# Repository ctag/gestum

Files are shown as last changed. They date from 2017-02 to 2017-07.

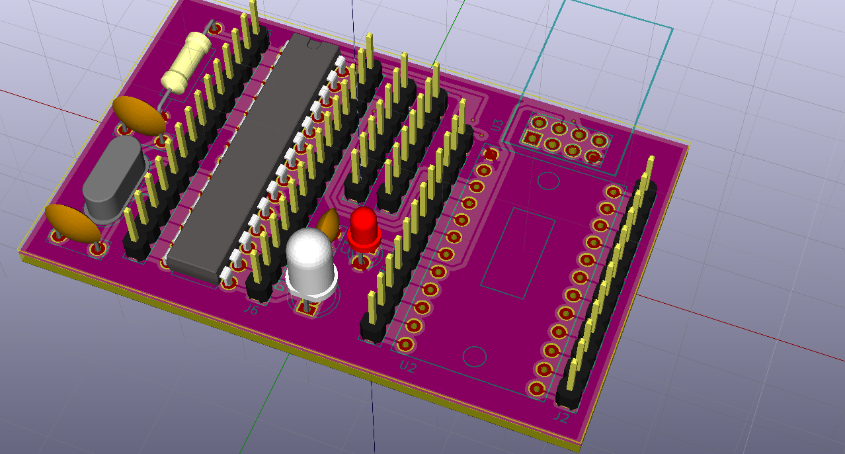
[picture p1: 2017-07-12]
kicad/opisthenar/image/board_render_3d.png

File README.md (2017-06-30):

# Space Sensei (せんせい)

*Firmware which automatically pairs Bosch SensorTec BNO055 library to any number of sensors and shuttles quaternions to a host computer.*

Learn from the sensei.

## Firmware setup

### Serial settings

38400 baud, 8N1

## TLV Packets

TLV (Type-Length-Value-Checksum) is used to minimize data required to send quaternions to host computer.

### Format

* Type - 1 byte opcode (e.g. 0x0C)
* Length - 1 byte unsigned int length of value field.
	* Note - Entire packet is always 'length + 3'
* Value - Raw bytearray.
* Checksum - 1 byte. Validates data integrity.https://68.media.tumblr.com/avatar_ef804b42fa43_128.png
	* Type + Length + [Value1 + Value2 + ValueN] + Checksum = 0x00

### Notes

* Not using preamble/postamble because timeout takes care of synchronization.
	* Timeout is ~30ms. So if comms go down, wait a while and try again.
* Not parsed without length byte.
	* Minimum packet length is 3 bytes.

### Opcodes

Even opcodes are master->mcu. Odd ones are mcu->master.

* 0x02: Heartbeat request (ping)
	* No Value field.
	* Packet: 0x0200FE
* 0x03: Heartbeat response (pong)
	* No Value field.
	* Packet: 0x0300FD
* 0x04: Request System State
	* No Value field.
	* Packet: 0x0400FC
* 0x05: Return System State
	* Value field is 1-2 uint8. 
	* See System state section below.
* 0x06: Request BNO count
	* No Value field.
	* Packet: 0x0600FA
* 0x07: Return BNO count
	* Value field is one uint8
* 0x08: Request BNO Calibration Status
	* Value field is uint8 index of BNO. Must be less than BNO count.
* 0x09: Return BNO Calibration Status
	* Value field is 4 uint8.
	* In order: accel, gyro, mag, sys.
	* Page 48 of datasheet for more.
* 0x0A: Request BNO Quaternion
	* Value field is BNO index.
* 0x0B: Return BNO Quaternion
	* Value field is quaternion. 4 bytes.
* 0xAA: Generic system error
* 0xAB: Generic system error
* 0xAC: Checksum error
* 0xAD: Checksum error
* 0xAE: Timeout with partial packet
* 0xAF: Timeout with partial packet

### System state

Sent as a uint8. Constructed such that any nonzero number indicates a problem (except bootup, which just means wait a bit).

* 0 - Everything's good
* 1 - Bootup (everything's still good)
* 2 - No BNOs detected during scan. Connect them and reboot system.
* 3 - Error initializing BNO. Cycle power to system. Should send erroneous BNO #.

## BNO055

We're using Bosch's BNO055 9-axis fusion IMU. It kinda sucks, and looks like this:

From Adafruit's website

It has a [datasheet](doc/datasheet.pdf), and [C microcontroller library](https://github.com/BoschSensortec/BNO055_driver), with a [3rd party guide](doc/IntegrateBNO055.pdf) to help you integrate the library to your project.

### Bootup

On boot the BNO automatically falls into calibration mode. The space sensei firmware will wait until the minimum (maybe) calibration is met. Then it will proceed to normal operation.

On the debugging hardware, an LED is yellow during calibration, then switches to green for normal operation.

For NDEF mode (which we're using) the most basic calibration required is magnotometer (rotate sensor 360 like a compass).

### Calibration

Also listed in BNO datasheet page 47. Reiterated here for convenience.

* Mag
	* Rotate sensor in a circle like a compass.
* Gyro
	* Place sensor in a stable position for a few seconds.
* Accel
	* Place the device in 6 different stable positions for a period of few seconds to allow the
accelerometer to calibrate.
	* Make sure that there is slow movement between 2 stable positions
	* The 6 stable positions could be in any direction, but make sure that the device is lying at
least once perpendicular to the x, y and z axis.

Calibration status (as returned by command) is 0-3 for each with 0 being uncalibrated and 3 being nicely calibrated.

## Timing

Atmega328 runs at 16,000,000Hz. 0.000000063 seconds per tick.

BNO supposedly runs in NDEF mode at 100Hz. Haven't determined if it can be polled faster than this but with only 100Hz worth of valid data.

Esp8266 runs at a hair faster than the 4th order element of the Laplace transform of the function which defines cumulative average lava flow rates in North America but only up to the 19th century. Which is to say it actually runs at 80Mhz but has a lot of firmware cruft and I have no idea if that's a net positive or not.

## ESP8266

[notes here](esp/esp.md)

## Dev Notes

* 3 BNOs + TCA mux is right at the edge of the max power draw for my ftdi cable..
* Dupont/header connections make i2c unreliable. For implementation either solder connections or remove any stress/movement in wire connections.
* Firmware startup has a ~1 second delay which allows BNOs to boot. Is mentioned in the BNO datasheet.

## To Do  

Explain checksumming

Add quaternion member byte order in return tlv

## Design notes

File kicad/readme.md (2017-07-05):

# KiCAD

These files contain the PCB designs for space sensei.

## Opisthenar

Opisthenar is the back of the hand, where we intend to mount the central processing and communication elements of this sensor network.

## Phalanx

Phalanges are the bone segments in fingers, where we intend to mount the individual BNO055 sensors that report back to the Opisthenar PCB.

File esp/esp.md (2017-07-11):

# ESP Link

Using esp-link firmware on Wemos D1 mini board (esp8266). Also works on ESP-01 (smaller board).

They're eccentric and I don't like them, just like Tingle here.

## Devices

We're using two types of ESP8266 boards: [D1 Mini by WeMos](https://wiki.wemos.cc/products:d1:d1_mini) and [ESP-01 by AI Thinker](http://ecksteinimg.de/Datasheet/Ai-thinker%20ESP-01%20EN.pdf).

WeMos D1 is good for debugging and testing, but I'd like a final product to have the esp-01 because it's much smaller.

Command to check flash memory size:

	esptool --port /dev/ttyUSB3 --baud 115200 flash_id

### D1 Mini

The D1 mini has 8MB of flash, runs at 80MHz, costs less than $10, and is pretty big. Can be programmed over built-in usb port. Accepts 3V3 or 5V VCC.

Image of D1 Mini

### ESP-01

The esp-01 has 1MB of flash, runs at 40MHz, costs less than $5 and is pretty small. Can be programmed with an [external FTDI adapter](http://www.14core.com/wiring-and-upgrading-the-esp8266-firmware-via-ttl-uart-bridge/) and a sacrifice to the gods of poor PCB design. Accepts only 3V3 officially... but will work with 5V and get scalding hot.

The ESP-01 has two onboard LEDs, red and blue. Red is connected to power, blue is connected to the board's TX.

ESP-link adds an external green LED for wireless status. It is active-low; 3.3V draw.

Image of esp-01

## Installation

From the [esp-link flashing guide](https://github.com/jeelabs/esp-link/blob/master/FLASHING.md), download release archive and extract it.

Command to flash D1 mini:

    esptool --chip esp8266 --port /dev/ttyUSB3 \
    write_flash -fm dio -fs detect -ff 20m \
    0x00000 boot_v1.6.bin 0x01000 user1.bin \
    0x3fc000 esp_init_data_default.bin 0x7e000 blank.bin \
    0x3fe000 blank.bin 

This command is a mash-up of the [instructions for flashing esp-link](https://github.com/jeelabs/esp-link/blob/master/FLASHING.md) and Wemos's d1 mini [flashing guide](https://wiki.wemos.cc/tutorials:get_started:revert_to_at_firmware).

Default AP ssid: `ESP_XXXXXX`

Command to flash ESP-01:

	esptool --chip esp8266 --port /dev/ttyUSB3 \
	write_flash -fm dio -fs detect -ff 40m \
	0x00000 boot_v1.6.bin 0x01000 user1.bin \
	0xfc000 esp_init_data_default.bin \
	0xfe000 blank.bin

Default AP ssid: `AI-THINKER_XXXXXX`

By default the esp-link firmware creates an AP which you connect to and then browse the 192.168.4.1 IP address's site, which is configuration for the system.

## Configuration

Connect to the `ESP-XXXXX` network. You should receive a DHCP address in 192.168.4.0/24.

The ESP runs mDNS, so you can connect to the ESP as either `esp-link` hostname or `192.168.4.1` IP address.

Telnet is primarily on port 23. There is a 5 minute timeout for inactivity, after which you need to reconnect.

I have debug logging turned off to keep junk from being sent to the microcontroller.

## Serial Connection

To connect the esp's telnet to a virtual serial port:

    sudo socat TCP4:192.168.4.1:23 PTY,link=/dev/ttyS0

Then open `/dev/ttyS0` with root.

If your machine uses generic DNS, then you can replace the above IP with the esp's mDNS hostname: `esp-link`

Reference:

http://technostuff.blogspot.com/2008/10/some-useful-socat-commands.html

Apparently you can also just use normal TCP, but I haven' tested it yet.

## Testing

With a simple loopback test (FTDI cable wired to the d1 mini) the latency from serial to telnet was imperceptible. Latency from telnet to serial was ~300ms.

## Dev Notes

esp-link will close the telnet connection after 5 minutes of inactivity. Be warned, software needs to be able to account for this and reconnect.

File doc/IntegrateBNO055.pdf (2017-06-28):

How to Integrate the Bosch BNO055 Library into your Tiva Launchpad Project A How-To Guide
By Phillip Dupree
Mechatronics Lord

So you want to integrate the BNO055 Bosch-Sensortec C Library into your Tiva Launchpad Project? You poor bastard. Good luck. Quick note before you get started, this guide should be extremely helpful in showing anyone how to integrate the Bosch bno055 library into their microcomputer project, regardless of whether they are using a Tiva Launchpad microcomputer or not. The microcomputer I’m using is the TM4C123GXL. Now let the games begin.

### Chapter 1: Preliminary Reading

1A: You’re In Trouble.
Because this is, unfortunately, a massive pain. But there is hope for you, especially if you’re extremely familiar with:
- I2C Protocol
- C Programming Language (advanced)
- TivaWare Library
- TivaWare I2C Library and what the I2CmasterControl Function is actually doing on an I2C Protocol level.
- The bno055 datasheet, particulary the section on I2C Communication.

If not, here is where you start.

1B: Get Reading
For I2C Protocol, this is a very good online tutorial that goes over both I2C Protocol and how to use the Tiva to set it up. The video is “TM4C123 Tutorial: I2C Communications” by AllAboutEE on Youtube. This dude is a baller and I want him to be my friend. Watch this video three or four times (seriously) and take notes. Once you actually feel comfortable with how I2C Protocol works (SCL line, SDA line, master, slave, acks, nacks, start bit, stop bit, etc), then move on. I highly recommend you google around and read a few articles on I2C Protocol as well to make sure everything is clicking.

Next move on to the tivaware library. Download the document “TivaWareTM Peripheral Driver Library: User’s Guide” from Texas Instruments. Skip to section 17: Inter-Integrated Circuit (I2C) and read up on all the functions. Spend a good time on the initialization functions and I2Cmaster Control.You should see how they do all the different things you learned about my studying I2C beforehand.

Unfortunately we’re not nearly done with absorbing all the information you’ll need to even stand a chance of integrating Bosch’s bno055 library into your project. It’s critical that you understand not just I2C protocol, but how the bno055 works with I2C. Can the bno055 handle successive reads and writes, or do you have to send and/or read one byte at a time? What clock rate does the bno055 require for its I2C communication? What is its default slave address? You get the point. Download the bno055 datasheet from Bosch-Sensortec or Adafruit. You really need to read it from cover to cover, but for now scour Section 4.6, I2C Protocol (referred to throughout the guide as 4.6). Read it again, and again. We’ll be referring back to this throughout the guide.

If you’re doing this right you should be seeing a problem by now. Now you know the specifics of how you write to the bno055 via I2C. Like, if you want to write a byte you have to send a start bit then, then the slave address, then get an ack back from the bno055, then send the register address, get an ack back, don’t send a stop bit yet, etc…but do you know how to do any of that? Not really. You have this big TivaWare functions that initialize I2C and send a slave address, data byte, then a nack, but you probably don’t know how to do complicated stuff like the Read of a bno055 register requires. Writing a slave address then register address, getting an ack back, being sure not to send a stop bit, then sending a read command + register address, etc..what you need to know is exactly what the I2C Master Control commands are doing. There are 8 of them, and to construct the bno055 i2c read and write functions you’ll need to know exactly what they do.

In order to do that, download “Using Feature Set of I2C Master on TM4C129X Microcontrollers” written by Amit Ashara, from the Texas Instruments website. It is an Application Report, SPMA073 – July 2015. Plug all that and it should pop up in google. Amit Ashara is a total badass who balls so hard, you don’t even know. He’s a huge help and lord and master of the TI forum. Read this document from cover to cover and cross-analyze it with the I2C Protocol section of the bno055 datasheet. You should now understand how, in order to send a write command, you’ll need to use the I2C Master Burst Send Start and Burst Send Finish commands, and for the more complicated bno055 read commands, you’ll need to use a combination of the Burst Send Start, Single Receive, Burst Receive Continuous, and Burst Receive Finish commands, depending on how many bytes you’re trying to read at once.

We’d be nearing the end if we were simply writing our own I2C Library using TivaWare to communicate with the bno055. And in a lot of ways, that would be much easier than what we are attempting to do. Stop here if you want to make a few read and write register fuctions. You now know enough to do so. But for you few brave souls who want to integrate Bosch Sensortec BNO055 sensor driver library into their projects, which will give you the ability to get huge amounts of data from the bno055 with one line function calls, then continue.

### Chapter 2: Shit Gets Real (The Library, What It Does, and Other Concerns)

2A: Getting Started. Download the driver library. It only consists of three files: bno055.h, bno055.c, and

bno055_support.c. Integrate the first two into your project as usual and don’t forget to add the include files into your relevant modules. Spend a lot of time reading through all three files. The support file is a rather nebulous cluster of badly written examples, while the first two are your standard library files.

First of all, download and read “BNO055 Quick Start Guide” from Bosch Sensortec. It’s only 9 pages so read it through several times spending most of your time on page 7, the example code (if you are unfamiliar with the bno055 to begin with this guide would be a good place to start). You should now understand that in theory, this library can make your life pretty easy, with powerful functions that allow you to change the mode and give you access to all the data the IMU has to offer. It’s a generic C library to go with any microcomputer, so all you really have to do is:
a. Copy the entire initialization routine from the Quick Start Guide (steps 1 – 5)
b. Select whatever mode you want and start calling functions to get your data
c. Figure out Step 3 in the Quick Start Guide example code, in which you write your own I2C Functions for reading and writing and link them to the API communication pointers. On the right side of these functions you insert your own i2c read and write functions (BNO055_I2C_bus_read and _write are just holders for your own functions.) Easy, right?

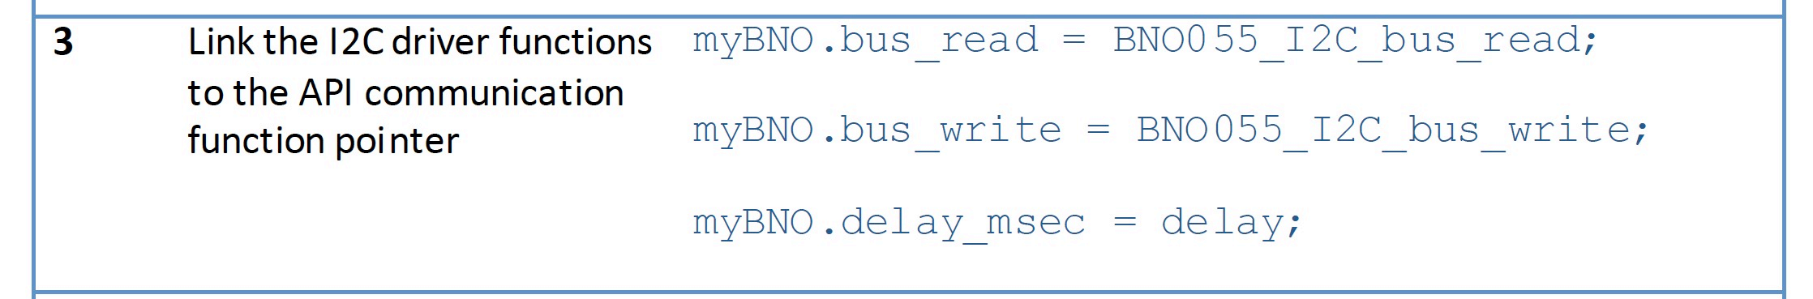
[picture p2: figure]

Figure 1: Example Code, Step 3

Hell no.

The problem is that how these functions need to be written is completely undocumented. What arguments do these functions require? Do they need to save their data to an array somewhere? What are they returning? Do they return anything? Do the functions need to be able to internally handle reading and/or writing multiple bytes?

You’ll have to parse together the answers to these questions and many more, in little infuriating painful bits in pieces, by reading 4.6 (which I’ve already had you study), and dragging yourself through the library files.

If your C is very good and you have no problem reading about structs and pointers, this library may be moderately straight-forward to you. If you’ve never used structs, pointers, referencing, passing, and that sort in your moderately simple C code before (like me), this library will be an unintelligible clusterfuck. Make no mistake, this library is advanced C. It’s not just you. So read through the library as best you can, take a break and get some coffee, then come back and spend a few hours reading about structs and pointers. Everything about pointers. Pointers and referencing, pointers as function arguments, pointers pointers pointers. Let it sink in. Write some simple example programs. Take another break, come back and read about pointers and arrays and pointers to an array. Let that sink in. Sleep on it all.

Now it’s morning and the library will make a bit more sense. I can’t explain to you very well how it works, but I can give you some ideas.

2B: The Header File
Open up bno055.h, the header file. A struct called bno055_t is created to hold all the core information of the chip, including the chip ID, softwar rev ID, i2c device address, and most importantly, the bus write and read function pointers. This struct is created in the header file under STRUCTURE DEFINITIONS.
There are structs created to hold the data from accelerometer, magnetometer, gyro, calibration, etc. These structs hold the different components for each of these measurements and are also found in the header file under STRUCTURE DEFINITIONS.

The pound defines (#define) for a hundred different things are found in the header file. If you’re confused by the u8, s8, etc, take a look at the top of the header file. All the pound defines for the registers are here as well.

2C: The Source File
Much more difficult is the actual library file bno055.c. This contains all the function calls. These functions work by taking in data, processing it, then passing it into the i2c read and write functions you crafted and linked to the API communication pointers, which in turn write to the bno055. Why is it done this way? Because the blessing and the curse of this library is that it is a generic library that can be interfaced with any microcomputer. The best way to understand this will be an example. I will explain as best I can.

The function bno055_init is near the top of bno055.c. This function initializes communication by setting the register page to zero and reading the chip ID, accelerometer revision ID, etc. Look at the line where it writes the default page as zero.

Figure 2: BUS_WRITE_FUNC 1

What’s going on here?

- This function, like all the communication functions, returns a variable com_rslt which stands for communication result.
- p_bno055 is a pointer to the bno055_t struct. This line of code is going into the bno055_t struct and “calling” (for lack of a better word) the BNO055_BUS_WRITE_FUNC pointer. This is nothing more than a pointer to the write function you wrote and linked to in Step 3 of the quick start guide (bus_write is pound defined as BNO055_BUS_WRITE_FUNC in the header file, so they are synonymous). So it is passing dev_addr, BNO055_PAGE_ID REG, &v_page_zero_u8, and BNO055_ONE_U8X into your function.
- So your i2c write function must have four arguments, but what do they mean?
- This is where a guide from bosch on how you must construct your i2c read and write functions in order to properly link them to their library would be great. Unfortunately, it doesn’t exist. All you have is me.

Just so we’re on the same page, here’s what we now know: We have a library from bosch full of powerful functions that should in theory make our lives easier. The problem is it’s a generic library, so we have to write our own low-level functions that read and write to the bno055 using I2C. If we can properly construct these functions and link them to the bosch library, our work is done and we can call all of bosch’s functions to set up the bno055 and get data from it. However, these functions have to be set up a very specific way – returning the right thing and taking the right arguments – to work with the bosch library. Exactly how they have to be specifically written is not documented so we have to figure it out from context and by reading the library. So onto Chapter 3.

### Chapter 3: How the Actual Fuck do we write our I2C read and write functions so that they’ll properly communicate with the bno055 library?

3A: Into the Support File
The file bno055_support.c has the best lead on how to write the I2C Read and Write functions, though it’s still phenomenally shitty. This text comes from towards the top of the file:

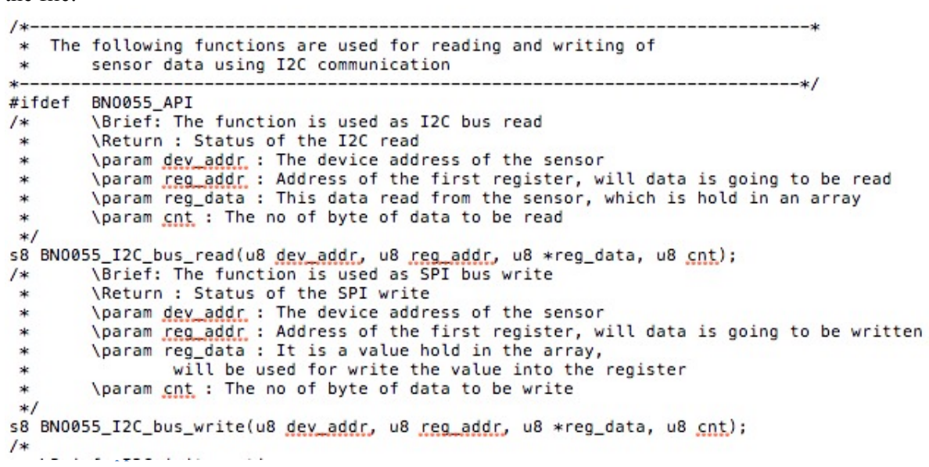
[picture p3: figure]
FIGURE 4: Support File Code

In badly written English this giving you invaluable insight into what your I2C bus read and write functions need to do and what arguments they must take. Now, this guide is getting a little long so I’m going to speed this up. What can we take away from this?

3B: The Return
First, these functions are not “void”. They return s8, which is a signed eight-bit integer which is the result of your I2C communication. I believe that 0x00 means no error, while anything else indicates an error of sorts. In my functions, I return I2CMasterErr from the TivaWare library. I can’t swear this is correct.

3C: The Arguments
Moving on. According to the support file, Both your read and write function take four arguments:
a. the slave device address (address of the bno055)
b. register address
c. data pointer
d. count variable. The first two are self explanatory.

Now a. and b. are self explanatory. The latter two are a bit more confusing. Let’s start with c. For the write function this is pretty simple. It is an eight bit variable that contains the data we want to write to the given register. You are not creating this variable – it is created within the higher functions that call your prewritten read and write functions. Why is it an address of a variable, rather than the variable itself like arguments a. and b? That’s just how the library functions are structured. The same concept goes for the read function, except now *reg_data is an array which can hold multiple bytes. You are not creating this array. Again, it is created within the functions. This took me ages to figure out. To demonstrate, let’s look at this function from bno055.c, the source file.

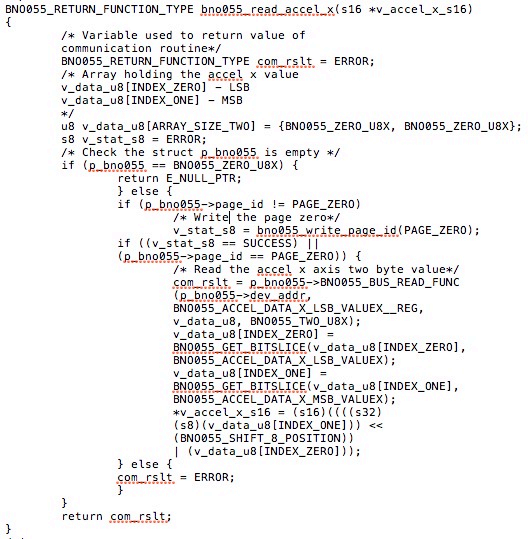
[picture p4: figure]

Notice how array “u8 vv_data_u8[arrray_size_two]” is created within the function before we start calling BNO055_BUS_READ_FUNC (which, of course, just links to your read function)? Something very similar happens when you take a look at a Write function within the library, except it’s just a u8 variable, not a u8 variable array.

Now for the count variable. This had me confused for ages. Remember when in Chapter 1 I had you read Section 4.6 (I2C Protocol) of the bno055 datasheet? You should recall from this that though we can read multiple bytes, we can only write one byte at a time. So why the hell is there a count variable for the write function? Answer: I honestly don’t know, but when I dug through the library I found that all the functions only input a “1” as the count variable. So my i2c write function actually doesn’t do anything with the count variable. So far I haven’t run into errors.

This is not the case with the read function. Take another look at the read_accel_x function and you’ll see that internal to your read function you must be able to read multiple bytes and store them in the data array that gets passed into the read function. You know from Section 4.6 of the bno055 datasheet that you can read more than one data byte at a time. Your read function will be a good deal more complicated than your write function. You will have to take in the count variable and do one thing if the count is only 1, and a more complicated routine is the count is more than one.
3D: In Retrospect

Let’s recap. For the READ FUNCTION:
- You must input the slave device address and the address of the register you wish to read from.
- You must take in the address of a reg_data array, and write the data you get back from bno055 into that array.
- Your read function takes in a count variable. It has to be smart enough to save multiple bytes of data, starting at the register address and incrementing from there. So if I input a register address of 0x00 and a count of 3, I have to be able to read from register 0x00, 0x01, and 0x02, and save it in reg_data[0] through [2].

For the WRITE FUNCTION:
- You must input the slave address and the address of the register you wish to write to.
- You must take in the address of a reg_data variable and write that data onto the register.
- You can ignore the count variable, though it must be included as a argument of your function.

That’s it. Write your read and write function. Link them to the API communication pointers as shown in Step 3 of the Quick Start Guide, described in Chapter 2 of this Guide. Compile your code and write to your heart’s content.

But Phillip, aren’t you going to include the code to your read and write functions?

No, because I’m a sadistic bastard. I’ve encapsulated a week of banging my head against a wall into this guide. I’ve given you all the tools you need in painstaking details. I’ve spent all day writing this guide when I could have been sleeping or actually getting ahead (or let’s face it, less behind) on my project. You can do this. Believe in me who believes in you. Here, however, is the argument line of both:

s8 bno_read(u8 dev_address, u8 reg_address, u8 *reg_data, u8 count){//magic} s8 bno_read(u8 dev_address, u8 reg_address, u8 *reg_data, u8 count){//more magic}

Now I’m going to get some goddamn coffee.

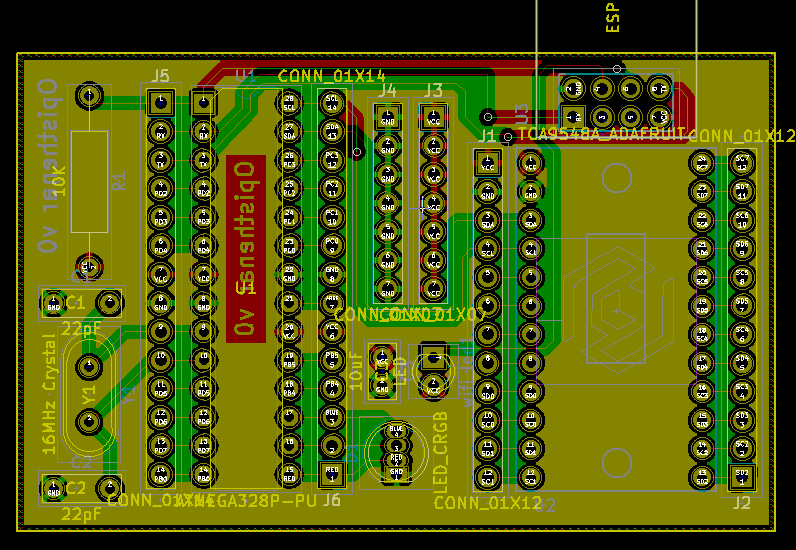
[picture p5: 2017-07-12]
kicad/opisthenar/image/schematic.png

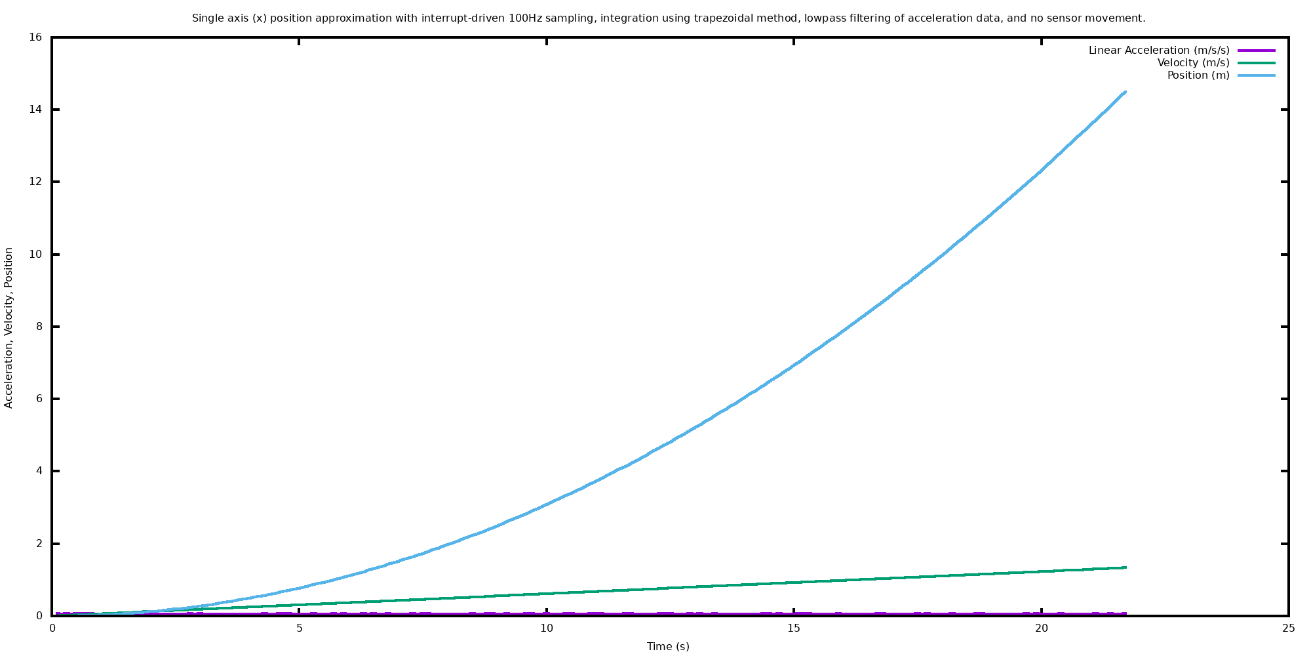
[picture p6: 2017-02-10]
plots/plot_4/plot.png

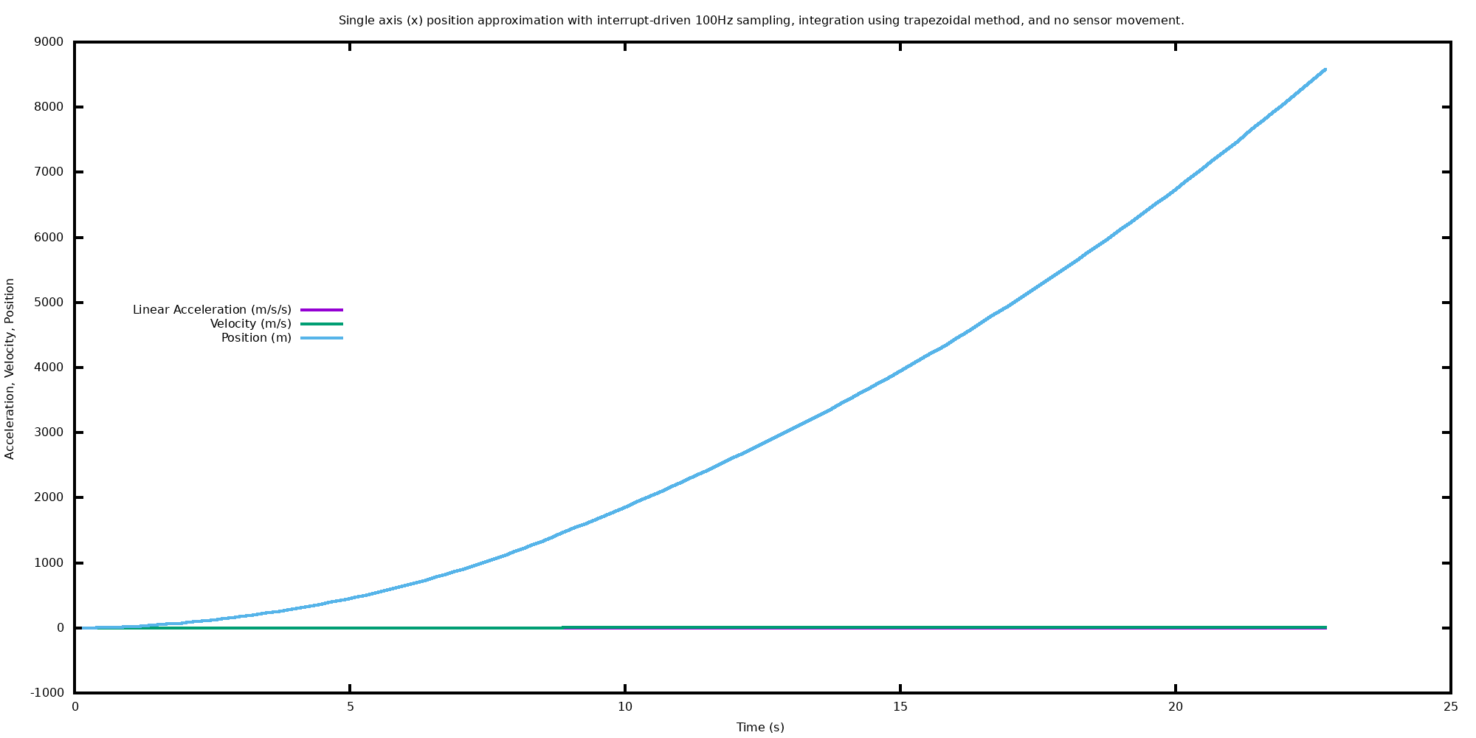
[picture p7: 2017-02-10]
plots/plot_3/plot.png

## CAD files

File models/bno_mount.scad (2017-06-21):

cube((1.05*2.54), (0.8*2.54), 5);

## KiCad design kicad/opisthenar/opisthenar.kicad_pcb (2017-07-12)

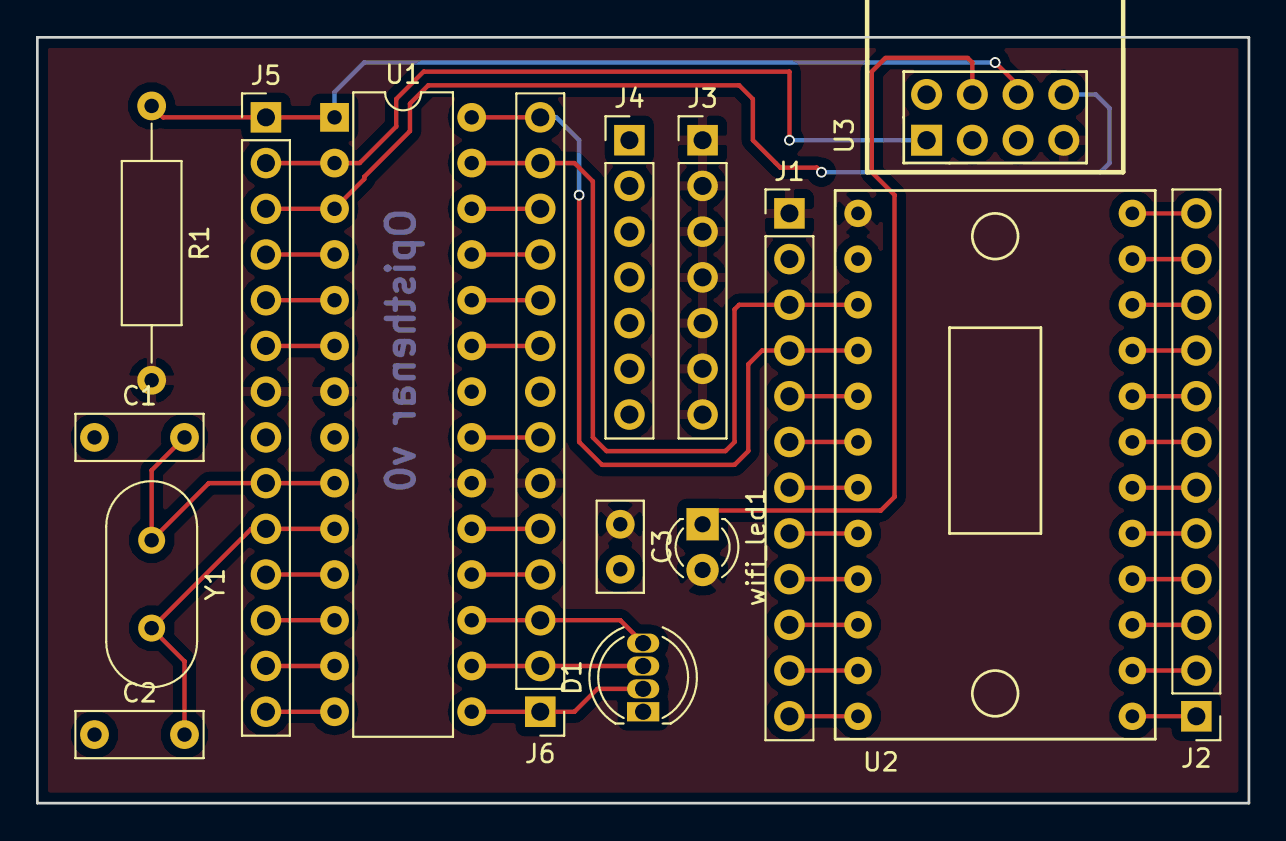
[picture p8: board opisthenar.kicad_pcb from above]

Board: 2 copper layers, 67.3 x 42.5 mm, 16 parts (0 on the bottom side), 47 nets.

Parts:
C1, C2: 22pF; C_Disc_D7.0mm_W2.5mm_P5.00mm
C3: 10uF; C_Disc_D5.0mm_W2.5mm_P2.50mm
D1: LED_CRGB; LED_D5.0mm-4
J1, J2: CONN_01X12; Pin_Header_Straight_1x12_Pitch2.54mm
J3, J4: CONN_01X07; Pin_Header_Straight_1x07_Pitch2.54mm
J5, J6: CONN_01X14; Pin_Header_Straight_1x14_Pitch2.54mm
R1: 10K; R_Axial_DIN0309_L9.0mm_D3.2mm_P15.24mm_Horizontal
U1: ATMEGA328P-PU; DIP-28_W7.62mm
U2: TCA9548A_ADAFRUIT
U3: ESP-01v090; ESP-01
Y1: 16MHz Crystal; Crystal_HC49-4H_Vertical
wifi_led1: LED; LED_D3.0mm

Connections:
/AREF: J6.7, U1.21
/BLUE: D1.4, J6.3, U1.17
/GREEN: D1.3, J6.2, U1.16
/PB0: J5.14, U1.14
/PB4: J6.4, U1.18
/PB5: J6.5, U1.19
/PC0: J6.9, U1.23
/PC1: J6.10, U1.24
/PC2: J6.11, U1.25
/PC3: J6.12, U1.26
/PD2: J5.4, U1.4
/PD3: J5.5, U1.5
/PD4: J5.6, U1.6
/PD5: J5.11, U1.11
/PD6: J5.12, U1.12
/PD7: J5.13, U1.13
/RED: D1.2, J6.1, U1.15
/RX: J5.2, U1.2, U3.1
/SC0: J1.10, U2.10
/SC1: J1.12, U2.12
/SC2: J2.2, U2.14
/SC3: J2.4, U2.16
/SC4: J2.6, U2.18
/SC5: J2.8, U2.20
/SC6: J2.10, U2.22
/SC7: J2.12, U2.24
/SCL: J1.4, J6.14, U1.28, U2.4
/SD0: J1.9, U2.9
/SD1: J1.11, U2.11
/SD2: J2.1, U2.13
/SD3: J2.3, U2.15
/SD4: J2.5, U2.17
/SD5: J2.7, U2.19
/SD6: J2.9, U2.21
/SD7: J2.11, U2.23
/SDA: J1.3, J6.13, U1.27, U2.3
/TCA_A0: J1.6, U2.6
/TCA_A1: J1.7, U2.7
/TCA_A2: J1.8, U2.8
/TX: J5.3, U1.3, U3.8
/XTAL1: C1.2, J5.9, U1.9, Y1.1
/XTAL2: C2.2, J5.10, U1.10, Y1.2
/~RESET: J5.1, R1.1, U1.1, U3.6
/~TCA_RESET: J1.5, U2.5
GND: C1.1, C2.1, C3.2, D1.1, J1.2, J4.1, J4.2, J4.3, J4.4, J4.5, J4.6, J4.7, J5.8, J6.8, U1.8, U1.22, U2.2, U3.2
unnamed: U3.4, wifi_led1.1
VCC: C3.1, J1.1, J3.1, J3.2, J3.3, J3.4, J3.5, J3.6, J3.7, J5.7, J6.6, R1.2, U1.7, U1.20, U2.1, U3.7, wifi_led1.2

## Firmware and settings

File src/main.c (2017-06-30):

/**
 * SPACE SENSEI - Let's learn about IMUs
 * Christopher Bero <csb0019@uah.edu>
 */

#include "main.h"

// Sensor scan addresses
const uint8_t tca_addr_list_len = 8;
const uint8_t tca_addr_list[] = {0x70, 0x71, 0x72, 0x73, 0x74, 0x75, 0x76, 0x77};

const uint8_t bno_addr_list_len = 2;
const uint8_t bno_addr_list[] = {BNO055_I2C_ADDR1, BNO055_I2C_ADDR2};

// Global variables
uint8_t accel_calib_status = 0;
uint8_t gyro_calib_status = 0;
uint8_t mag_calib_status = 0;
uint8_t sys_calib_status = 0;
struct bno055_quaternion_t quat = {0};

unsigned char input_buffer[16] = {0};
uint8_t input_index = 0;
#define INPUT_TIMEOUT 5
uint8_t input_timeout = 0;

#define SYS_STATE_OK 			(0)
#define SYS_STATE_BOOTUP 		(1)
#define SYS_STATE_ERR_NO_BNO 	(2)
#define SYS_STATE_ERR_BNO_INIT 	(3)
uint8_t system_state = SYS_STATE_BOOTUP;

#define CMD_PING			(0x02)
#define CMD_GET_STATE 		(0x04)
#define CMD_GET_BNO_COUNT	(0x06)
#define CMD_GET_BNO_CALIB 	(0x08)
#define CMD_GET_QUAT		(0x0A)
#define CMD_ERR_GEN			(0xAA)
#define CMD_ERR_CHK			(0xAC)
#define CMD_ERR_TMOUT		(0xAE)

// Function declarations
void send_packet(uint8_t opcode, uint8_t len, uint8_t * data);
void proc_input();

uint8_t tcaselect(uint8_t tca_addr, uint8_t mux) {
	uint8_t err = 0;
	if (mux > 7) return 1;

	err = i2c_start(tca_addr, I2C_WRITE);
	err += i2c_write(1 << mux);
	i2c_stop();

	return err;
}

uint8_t led_set(uint8_t red, uint8_t green, uint8_t blue)
{
    OCR1A = red;
    OCR1B = green;
    OCR2A = blue;
    return(0);
}

void led_enable()
{
    // Red   - Timer 1A
    // Green - Timer 1B
    // Blue  - Timer 2A
    TCCR1A = (1 << COM1A1) | (1 << COM1B1) | (1 << WGM10);
    TCCR1B = (1 << CS10);
    TCCR2A = _BV(COM2A1) | _BV(WGM20);
    TCCR2B = _BV(CS20);
}

void led_disable()
{
    TCCR1A = 0x00;
    TCCR1B = 0x00;
    TCCR2B = 0x00;
}

/* Init
 * This function is kept over from the Arduino library for no reason.
 * I have arbitrarily decided that it will be used to initialize
 * low level hardware.
 */
void init ()
{
	// LED pin setup
	DDRB = (1<<PIN1) | (1<<PIN2) | (1<<PIN3);
	led_enable();
	led_set(0, 0, 0);

	// Timer0B setup
	TCCR0B = (1 << CS02) | (1 << CS00);
	TCNT0 = 0;
	OCR0B = 156; // 10ms polling
	TIMSK0 = (1<< OCIE0B);
}

void setup()
{
	int8_t err = 0;
	cli();
	wdt_disable();

	led_set(5, 5, 0);

	usart_init();
	init_printf(NULL, usart_putchar);
//	printf("Printf init.\n");
	i2c_init();
//	printf("i2c init.\n");

	// POR setup time from datasheet
	for (uint8_t i = 0; i < 100; i++)
	{
		proc_input();
		_delay_ms(10);
	}

	led_set(25, 25, 0);

	for (uint8_t tca_i = 0; tca_i < tca_addr_list_len; tca_i++)
	{
//		printf("Checking TCA address 0x%02X\n", tca_addr_list[tca_i]);
		err=i2c_start(tca_addr_list[tca_i], I2C_READ);
		i2c_stop();
		if (err)
		{
//			printf("\tNo TCA found.\n");
			continue;
		}
		for (uint8_t mux_i = 0; mux_i < 8; mux_i++)
		{
			tcaselect(tca_addr_list[tca_i], mux_i);
			for (uint8_t bno_i = 0; bno_i < bno_addr_list_len; bno_i++)
			{
				err=i2c_start(bno_addr_list[bno_i], I2C_READ);
				i2c_stop();
				if (!err)
				{
					bnoList_append(tca_addr_list[tca_i], mux_i, bno_addr_list[bno_i]);
//					printf("Found BNO 0x%02X at index %d on TCA 0x%02X\n", newBno->bnoPtr->dev_addr, newBno->tca_index, newBno->tca_addr);
				}
				proc_input();
			}
		}
	}

	if (!root)
	{
		led_set(25, 0, 0);
		system_state = SYS_STATE_ERR_NO_BNO;
		while(1)
			proc_input();
	}
	else
	{
		struct bnoList_t * tmpBno = root;
		while (tmpBno)
		{
//			printf("Bno: %d; 0x%02X addr at TCA 0x%02X\n", tmpBno->tca_index, tmpBno->bnoPtr->dev_addr, tmpBno->tca_addr);
			tcaselect(tmpBno->tca_addr, tmpBno->tca_index);
			err=bno055_init(tmpBno->bnoPtr);
//			printf("bno init: %d\n", err);
			err+=bno055_set_power_mode(BNO055_POWER_MODE_NORMAL);
//			printf("bno power mode: %d\n", err);
			err+=bno055_set_operation_mode(BNO055_OPERATION_MODE_NDOF);
//			printf("Set bno operating mode: %d\n", err);
			if (err)
			{
				led_set(25, 0, 0);
				system_state = SYS_STATE_ERR_BNO_INIT;
				while(1)
					proc_input();
			}

			do
			{
//				led_set(25, 25, 0);
//				printf("\nCalibrating sensor %d:\n", tmpBno->tca_index);
				err=bno055_get_accel_calib_stat(&accel_calib_status);
//				printf("\tAccel: %d [%d]\n", accel_calib_status, err);
				err=bno055_get_mag_calib_stat(&mag_calib_status);
//				printf("\tMag: %d [%d]\n", mag_calib_status, err);
				err=bno055_get_gyro_calib_stat(&gyro_calib_status);
//				printf("\tGyro: %d [%d]\n", gyro_calib_status, err);
				err=bno055_get_sys_calib_stat(&sys_calib_status);
//				printf("\tSys: %d [%d]\n", sys_calib_status, err);
//				_delay_ms(500);
				proc_input();
			} while (sys_calib_status != 3 || err != 0);

			tmpBno = tmpBno->nextPtr;
		}
	}

	sei();
	led_set(0, 25, 0);
	system_state = SYS_STATE_OK;
}

uint8_t get_quaternion()
{
	uint8_t err = 0;
//	err+=bno055_get_accel_calib_stat(&accel_calib_status);
//	err+=bno055_get_mag_calib_stat(&mag_calib_status);
	err+=bno055_get_gyro_calib_stat(&gyro_calib_status);
	err+=bno055_get_sys_calib_stat(&sys_calib_status);

	if (gyro_calib_status >= 2 && err == 0)
	{
		bno055_read_quaternion_wxyz(&quat);
		return 0;
	}
	else
	{
//		printf("Device uncalibrated.\n");
		return 1;
	}
}

uint8_t checksum_valid()
{
	uint8_t checksum = input_buffer[0];
	uint8_t len = input_buffer[1]+2;
	for (uint8_t index = 1; index <= len; ++index)
	{
		checksum += input_buffer[index]; // All bytes XOR'd should = 0x00
	}
	if (checksum == 0x00)
	{
		return 0; // checksum is good
	}
	else
	{
		return 1;
	}
}

void send_packet(uint8_t opcode, uint8_t len, uint8_t * data)
{
	uint8_t checksum = 0xff;
	opcode += 1; // Responses are odd numbered.
	checksum += opcode;
	usart_putchar(NULL, opcode);
	checksum += len;
	usart_putchar(NULL, len);
	for (uint8_t index = 0; index < len; index++)
	{
		checksum += data[index];
		usart_putchar(NULL, data[index]);
	}
	usart_putchar(NULL, ~checksum);
}

void send_pong()
{
	send_packet(CMD_PING, 0, NULL);
}

void send_system_state()
{
	send_packet(CMD_GET_STATE, 1, &system_state);
}

uint8_t get_num_bnos()
{
	uint8_t count = 0;
	struct bnoList_t * tmpBno = root;
	while (tmpBno)
	{
		count++;
		tmpBno = tmpBno->nextPtr;
	}
	return count;
}

struct bnoList_t * get_bno(uint8_t index)
{
	uint8_t count = 0;
	struct bnoList_t * tmpBno = root;
	while (tmpBno && count < index)
	{
		count++;
		tmpBno = tmpBno->nextPtr;
	}
	return tmpBno;
}

void send_num_bnos()
{
	uint8_t count = get_num_bnos();
	send_packet(CMD_GET_BNO_COUNT, 1, &count);
}

void send_bno_calib(uint8_t index)
{
	int8_t err = 0;
	struct bnoList_t * bno = get_bno(index);
	uint8_t calib_array[4];
	tcaselect(bno->tca_addr, bno->tca_index);
	err=bno055_get_accel_calib_stat(calib_array);
	err=bno055_get_mag_calib_stat(calib_array+1);
	err=bno055_get_gyro_calib_stat(calib_array+2);
	err=bno055_get_sys_calib_stat(calib_array+3);
	send_packet(CMD_GET_BNO_CALIB, 4, calib_array);
}

void send_quat(uint8_t index)
{
	int8_t err = 0;
	struct bnoList_t * bno = get_bno(index);
	tcaselect(bno->tca_addr, bno->tca_index);
	get_quaternion();
	send_packet(CMD_GET_QUAT, 8, (uint8_t *)&quat);
}

void send_err(uint8_t err)
{
	send_packet(err, 0, NULL);
}

void proc_input()
{
	char input_char;
	if(usart_getchar(&input_char))
	{
		if (input_timeout > INPUT_TIMEOUT)
		{
			if (input_index > 0)
			{
				send_err(CMD_ERR_TMOUT);
			}
			input_timeout = 0;
			input_index = 0;
		}
		return;
	}
	input_buffer[input_index] = input_char;
	if (input_index >= 2) // minimum length: 3
	{
//		printf("len: %d\n", input_buffer[1]);
		uint8_t len = input_buffer[1];
		if (input_index == (len + 2)) // data len + type/len/chk bytes
		{
//			printf("Passed len check.\n");
			// Check checksum, run command
			if (checksum_valid() == 0)
			{
//				printf("passed checksum validation.\n");
				if (system_state == 1)
				{
					switch(input_buffer[0])
					{
						case CMD_GET_STATE: // Get sys state
							send_system_state();
							break;
						default:
							send_err(CMD_ERR_GEN);
							break;
					}
					input_index = 0;
					return;
				}
				if (system_state >= 1)
				{
					switch(input_buffer[0])
					{
						case CMD_GET_STATE: // Get sys state
							send_system_state();
							break;
						default:
							send_err(CMD_ERR_GEN);
							break;
					}
					input_index = 0;
					return;
				}
				switch (input_buffer[0])
				{
				case CMD_PING: // Ping
					send_pong();
					break;
				case CMD_GET_BNO_COUNT: // Get num bnos
					send_num_bnos();
					break;
				case CMD_GET_STATE: // Get sys state
					send_system_state();
					break;
				case CMD_GET_BNO_CALIB: // Device calibration status
					{
						if (len != 1) // Must provide BNO index.
						{
							return;
						}
						uint8_t index = input_buffer[2];
						if (index >= get_num_bnos())
						{
							return;
						}
						send_bno_calib(index);
						break;
					}
				case CMD_GET_QUAT:
					{
						if (len != 1) // Must provide BNO index.
						{
							return;
						}
						uint8_t index = input_buffer[2];
						if (index >= get_num_bnos())
						{
							return;
						}
						send_quat(index);
						break;
					}
				case CMD_ERR_GEN:
					{
						// OK?
						break;
					}
				default:
					send_err(CMD_ERR_GEN);
					break;
				}
				input_index = 0;
				return;
			}
			else
			{
				send_err(CMD_ERR_CHK);
			}
		}
	}
	input_index++;
}

/* Loop
 * Does all of the main tasks.
 */
void loop()
{
	proc_input();
}

/* Main
 * This function is used to override main() provided by the Arduino library.
 * It simply structures the other high-level functions.
 */
int main(void)
{
	init();

    setup();

    for (;;)
    {
        loop();
    }

    return 0;
}

// Interrupt vector
ISR(TIMER0_COMPB_vect)
{
	input_timeout++;
}

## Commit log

2017-02-02 Framework, codeblocks project.
2017-02-02 Brought in i2c library
2017-02-02 Tied in i2c functions.
2017-02-02 printf support.
2017-02-10 interrupt driven timing.
2017-02-10 Hold for calibration on boot
2017-02-10 Trapezoidal integration, arithmetic fix, and lowpass filtering.
    [main.c]
2017-02-10 Fixed error in integration.
    [main.c]
2017-05-30 Testing workaround for bno driver.
2017-05-31 Example auto-detect for bno and mux chains.
2017-05-31 Be careful about sporadic behavior caused by current draw.
2017-06-02 Notes from debugging i2c today.
2017-06-21 output timer
2017-06-21 Fixed compiler error for signed char comparison.
    [main.c]
2017-06-21 Switched to quaternions.
2017-06-21 Added 3d finger-mount model.
    [bno_mount.scad]
2017-06-21 Removed code for euler, timerb, port outputs.
2017-06-29 Set timeout as timerB, removed debugging statements.
2017-06-29 Implemented basic error command.
    [main.c]
2017-06-30 bugfix to return system state.
    [main.c]
2017-07-05 Added pinboard PCB for reconfiguration.
    [opisthenar.kicad_pcb, opisthenar.sch]
2017-07-05 Added comparison of esp boards.
2017-07-05 Organizing pcb folder.
    [opisthenar.kicad_pcb, opisthenar.sch]
2017-07-10 Added TCA to kicad schmatic
    [opisthenar.kicad_pcb, opisthenar.sch]
2017-07-11 esp led notes.
2017-07-11 Added esp-01 to schematic.
    [opisthenar.sch]
2017-07-12 Updated opisthenar pcb for new pcb run.
    [opisthenar.kicad_pcb, opisthenar.sch]
